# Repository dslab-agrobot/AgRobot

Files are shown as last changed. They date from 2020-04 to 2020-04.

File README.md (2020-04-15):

# AgRobot
Repository for DSLAB AgRobot Project
The file structure should be:

```
.
├── LICENSE
├── README.md
├── doc
│   ├── design
|   ├── hardware
│   ├── implementation
│   ├── integration
│   ├── investigation
│   ├── literature
│   ├── other
│   ├── requirements
│   ├── testing
│   ├── validation
│   └── verification
├── pm
│   ├── meeting_minutes
│   ├── pm_docs
│   ├── progress_documentation
│   └── working_instructions
├── share
│   └── images
│       └── progress
│           └── photos
└── src
    ├── hardware
    ├── management_scripts
    ├── software
    └── tools
```

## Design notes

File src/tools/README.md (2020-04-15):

## Tools

Tools for AI , Embed ,etc
<br>
Each script offer an operation , not a piece of job .

### Table of Contents

  * [AI]
    + [Capture and join pictures(or video) from cameras](imgRec.py)
    + [Capture pictures from camera(shell)](imgRec.sh)
    + [List all USB-device with name](listall.sh)
    + [Simple test for a camera](mag.py)
  * [Embed]
    + [Send cmd to serials (python3)](connector.py)
    + [Send cmd to serials (shell)](file_sender.sh)
  * [Other]
    + [Rename photos for branch share](rename.py)

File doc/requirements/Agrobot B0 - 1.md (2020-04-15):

# Agrobot B0 - Requirements

```
Author: Nicholas Mc Guire
Review: 0.2
Date: May 7, 2019
Expires: Nov 8, 2019
Keywords: B0 requirements, basic data aquisition only.
Status: initial draft, unreviewed
DLC Phase: requiremnts
Ref: TODO add HW manuals
QA: initial review
Tracking: GIT
Format: ascii text
```

## Outline:

Basic collection of requirements based primarily on discussions and
team-meetings as well as some preliminary experimentation to gain rough
limits. These requirements serve as the basis for the design,
implementation and initial operation phase of B0.

## Intent of B0:

  Provide minimal mechanical and electrical/electronic support for
  data quisition on a fixed (track-based) potato-"field" while
  assuring basic (minimal) safety properties.

## Software controlor (Arduino)

 ### Arduino startup 
   - Provide ready signal once booted ? e.g. Pi can 
     request status -> response ready-for-command, busy-calibrate or
     error-state (to be defined !)
 ### Control of 4 drive-motors 
   - Input (from Pi3) relative motion distance/direction e.g.
     (+10cm/-20cm) 
   - Reset information (at end of track) to Pi ?? open-issue
   - Accuracy over the entire track (12m) +/- 3m (durable ?)
 ### Control of y-axis sled motor
   - Input (from Pi3) relative motion command (e.g. +5cm/-10cm)
   - Response Ack (e.g. 0 ok, -1 failed to execute command or
     error code about the failure 1 reset ?? TBD)
   - Reset information to Pi ?? open-issue
   - Accuracy over the entire sled (1m) +/- 2m (duable ?)
 ### Continuous check of end-pos sensors
   - (TOF Ultrasound for X-axis)
   - Read-contacts for y-axis (in discussion)
   - End bumpers on y-axis (ruber aprox 2cm)
   - End wheel catchers for X-axis in dicussion)
 ### Motion requirements
   - X-axis maximum speed 50-80 cm/min
   - Y-axis maximum 30cm/min (roughly 3 minutes for a left-right pass)
   - Reset of absolute 0 every 5m (2.5 passes ? or make that 6m and 
     3 full passes ?)
 ### Power Management requirements 
   - 5V supply for
        - Arduino
        - Raspberry Pi3
        - servo-motors 
        - LEDs
   - 30V for motors (?)
   
    Power supplies need to be sufficiently independent with respect
    to disturbances (notably the 30V!) TBD specify tollerances
    Voltage regulators for 5V and 30V shall be provided on-board
    based on 220V/60Hz source (atleast thats what I think china
    uses ?)

## Mechanical motion requirements

 The track (X-axis) is covered from end-to-end
   - Total travel time roughly 1h
 The sled (Y-axis) is covered from end-to-end
   - a pre-specified (static) number of halting positions is defined
   - continuous motion in discussion
 2 Cameras can be mounted on the Y-axis (USB connected to Pi3) 
 Side-guards on all 4 wheels
   - possitional accuracy on the track +/- 2cm
 Cable caryiage - power and network
 End-plates for reliable ultrasound reflection
   - Material (Al probably ?) TBD
   - Diameter 15cm ? TBD 
 Motors outward oriented - no collision with plants
   - Wheels "point" inward 

## Structural mechanics requirements (bot)

 headway/headroom: (over track) 80-90cm (all structural elements - not 
   counting sensor/actor fixtures)
 clear width: 100cm (ideally the wheels are the inner most point - which
   may be a bit below 100cm (95-96cm clear width between wheels)
 structural length <= 90cm total (including wheels !)
 top-torsion structure
   - couble-frame cage (possibly with surface re-inforcement pannels)
   - height 10-15cm
   - single (uninterrupted) beams on each side
   - corner re-inforcmenets "on demand" TBD
 Whele legs - bending limits/deflection under assumed maximum force (TBD !)
   - sidewards (Y-direction deflectino <= 1cm ?? can we put a lower bound
     on this ?
   - longitudinal (X-direction) deflection <= 0.5cm - if needed insert an
     additional stiffening element between the legs.

## Structural requirements bed

 Soil container dimensions 12x1*0.45m (initially 0.5 but reduced due to
   material availability)
 Double water protection in-side (silicon paint + plastic cover)
 Load distribution to cover 18 m^2 (<= 300kg/m^2 - which is for sure
   below load limits of the roof)
 Side props to support soil pressure (depends on board dimensions and
   quality)
 Tracks on both length side 
   - Min width 7-8cm
   - Surface plane +/- 1cm over the lenthg (should be achievable)
   - One-sided tape-mount for position recording (X-axis)
 Power rail (suspension) for draging of power/network cable
   (drag chain cable carrier or 
 Cabling requirements 
   - Electric cabling provided (220V)
   - Network (100Mbit ?) provided
   - other TBD

## Safety requirements

 The robot frame structure must be grounded !
 The cable caryiage must be grounded !
 The network cable shall be reasonably potential free (Tollerance TBD)
 All power cables shall be protected by adequate cable strain reliefs

Structural mechanics requirements (bot)
 USB cables shall be supported by a kinematic support (or similar)
   to ensure that sled movement can not damage/squeeze the 
   cabling
 Servo cables ? length limit ? TBD - not clear if the servos
   can be connected over 1.2m cable length (voltage drop ?)
 Ultra-sound receiver cables - length limit ? TBD
 I2C <-> PWN-controller cable - mechanical stability TBD

## Application sensor/actor requirements

 Low resolution camera capturing track position (tape) 
 
 ### Condition monitoring
   - Humidity sensor - Accuracy ??
   - Temperature sensor - Accuracy ??
   - Air pressure sensor - Accuracy ??
   - Sample rate 4-6 times per day (TBD)
 ### High-resolution camera for still pictures
   - 1280/720 minimum 
   - 24 bit color resolution
 ### High-resolution camera for video
   - FPS ??
   - resolution ??
   - Format ??
 ### LED lines
   - R/G/B other ?
   - brightness control (e.g. PWM)
 ### 2-axis servo for camera gimbal
 Structural mechanics requirements sensor mounting
   - Still image camera Y-axis sled mounted with  U/V rotation (180)
   - Video camera Y-axis firm straight-down mount
   - stationary low-res Video camera mount-point on leg 10-15 cm 
     above track (test focus range needed)

## Imaging requirements

 Still-image rate ?
 Video format 
 Storage format

## Application processor requirements (Pi3)

 ### Communication/synchronisation Arduino
   - Communication via serial line - clear-text - no security requirements
     o data CRC ?
   - Command send and status receive
     o loging of command sequence
   - Camera imaging commands (synchronized with arduino potition control)
   - Camera gimbaling control and angular recording (probably in image name
     TBD)
 ### Communication requirements Server
   - 100 Mbit or Gbit connection 
   - SSH server 
     o remote login support for non-root user
     o pre-exchanged keys 
     o DSA keys
   - rsync support: rsync over ssh for data retrival (pull from server)
   - defined security policy (TBD)
 ### Sensor handling
   - manage all sensors (implemented in python)
     o I2C bus configuration and handling
     o USB configuration and handling
   - manage LEDs (collor/intensity and sync with imaging subsystem)
 ### Data aquisition and handling
   - dedicated storage media for sensor data (not on root fs)
   - high-resolution and low-resolution camera + still-image camera
   - storage of a full track run locally (estimation:
     o still image <=5 images per y-axis transit, <=50 positions along
       the track - image size (jpeg) <= 500k -- 125MB per full track
       transit.
     o high-resolution vide 30GB per full track transit ??
   - Environment data sensor recording
 ### System monitoring
   - Standard Linux system records (syslog/klog/last)  

## Server requirements

Management data requirements
 ### Weather records for Lanzhou (general - public available records)
   - preferably with a local stored daily weather record
 ### Watering records
   - Amount (number of watering cans - roughly equally filled)
   - Time (+/-30min)
   - Person
 ### Operations records
   - Number of traversals and time and any anomalies
   - Number of photos/video-length per traversal and any anomalies
   - Number of environment sensor records and any anomalies
   - Motion record
     o Motion accuracy at end of track (X-axis)
     o Motion accuracy at reset of sled (Y-axis) roughly how many steps
       needed to reach end-indicator
     o Any abnormal termination of motion    
   - Server record
     o Recording of any operational anomalies related to
       data loss or authentication violation

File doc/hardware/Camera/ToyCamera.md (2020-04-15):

# List

|Name|ShopLink|Note|Num per camera|
|---|---|---|:---:|
|1.Electric focus lens|[Link](https://item.taobao.com/item.htm?spm=a1z09.2.0.0.7d312e8dXiKq8g&id=540927166249&_u=e23cfj5gcc23)|The best one I found in Taobao|1|
|2.Mini step motor driver|[Link](https://item.taobao.com/item.htm?spm=a1z09.2.0.0.7d312e8dXiKq8g&id=572946913506&_u=e23cfj5g69f9)|enough for test|2|
|3.M14 lens base|[Link](https://item.taobao.com/item.htm?spm=a1z09.2.0.0.7d312e8dXiKq8g&id=561669140255&_u=e23cfj5g5a85)|rely on the lens |1|
|4.USB camera module|[Link](https://item.taobao.com/item.htm?spm=a1z09.2.0.0.7d312e8dXiKq8g&id=530503001592&_u=e23cfj5g37c6)|rely on the lens|1|
|5.5v 4count delay|[Link](https://detail.tmall.com/item.htm?id=41231430731&spm=a1z09.2.0.0.7d312e8dXiKq8g&_u=e23cfj5g74d2)|cheap and Free freight|1|
|6.other|cables |DuPont wire, terminal wire, heat shrinkable tube, electric iron sleeve, cardboard sleeve (used to make shell)|NaN|

# Details

[jxt's blog](http://www.lolisaikou.cn/archives/diy%E5%8F%AF%E6%8E%A7%E5%85%89%E5%AD%A6%E5%AF%B9%E7%84%A6%E5%8F%98%E7%84%A6usb%E7%9B%B8%E6%9C%BAver01)

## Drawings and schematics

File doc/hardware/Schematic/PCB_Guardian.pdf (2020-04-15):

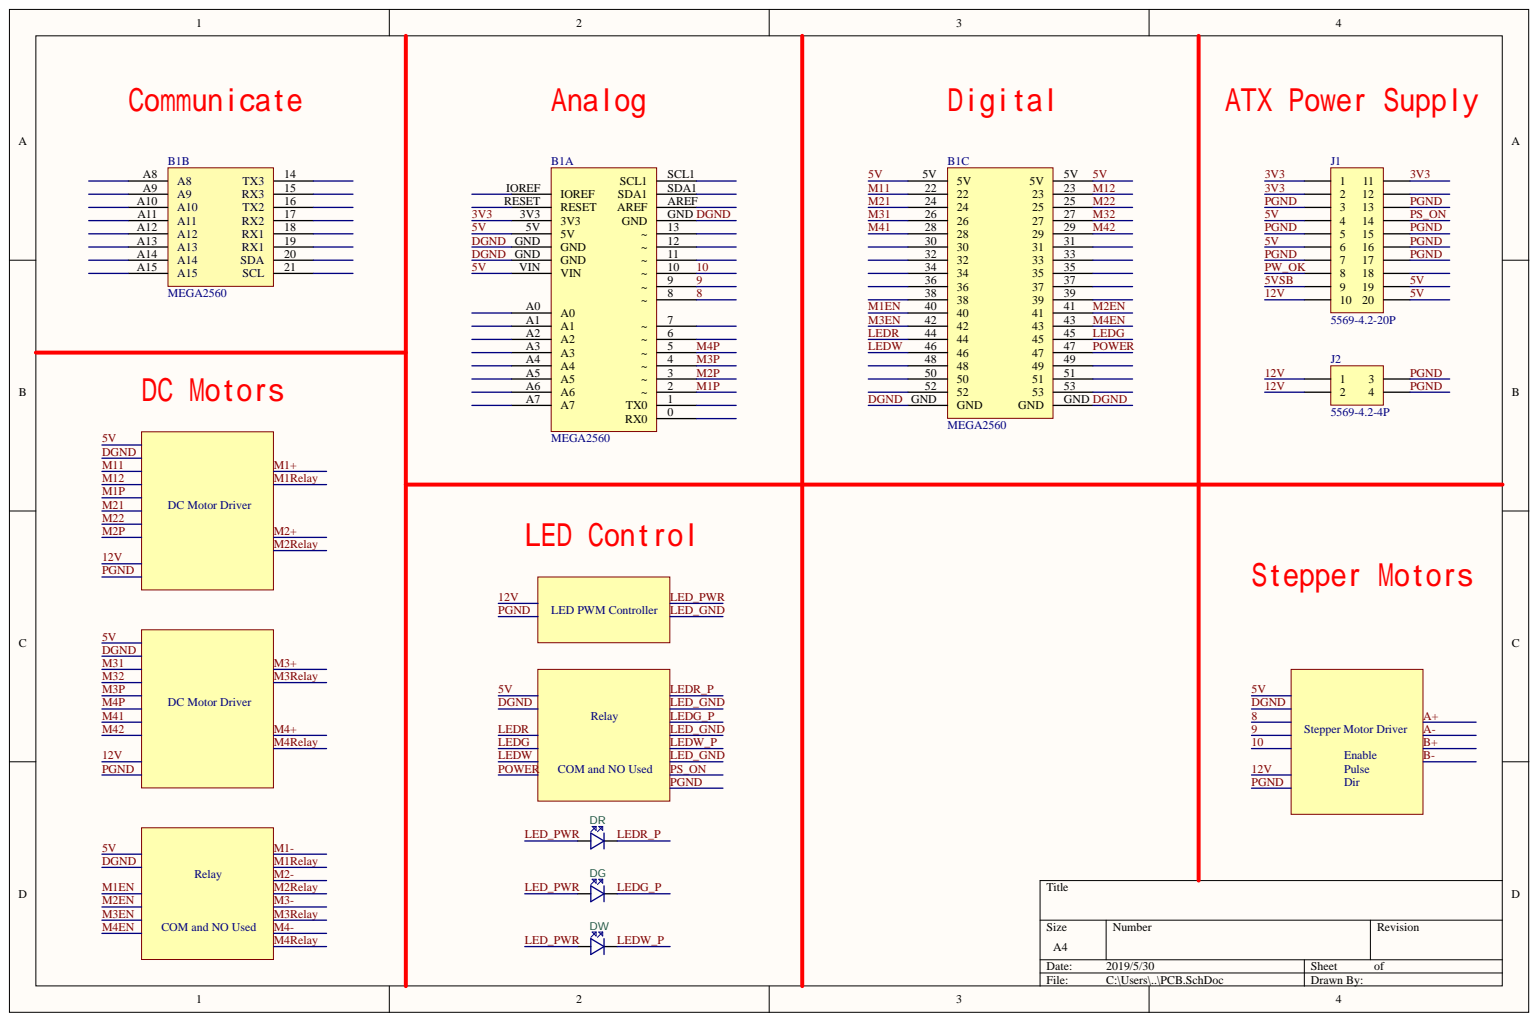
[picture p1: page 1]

COM and NO Used

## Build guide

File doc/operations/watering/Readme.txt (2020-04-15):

This directory saves and updates the record of potato-watering per 3 days.
watering amount was adjusted to 60L/3-days by the biology department members of the project

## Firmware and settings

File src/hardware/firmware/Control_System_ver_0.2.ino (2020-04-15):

/*
   Control System Source Code

                  Version 0.2


   FINISHED

   1. LED and POWER control Function is now added.

   2. Add software limitation to avoid wrong move commands.

   3. Use Hardware limitation to help calibrate the Y-axis.


   TO DO

   1. Add RELIABLE sensor to mesure the distance to the end of the track.



*/
#include <Wire.h>

//Digital Input Pins

//Define Pin Locations for Motors

//DC Motor Pins
//DC Motor 1 for Left-Front Wheel
#define M11 22
#define M12 23
#define M1P 2

//DC Motor 2 for Right-Front Wheel
#define M21 24
#define M22 25
#define M2P 3

//DC Motor 3 for Left-Rear Wheel
#define M31 26
#define M32 27
#define M3P 4

//DC Motor 4 for Right-Rear Wheel
#define M41 28
#define M42 29
#define M4P 5

////Stepper Motor Pins
////Stepper Motor 1 and 2 for X Axis
//#define S1D 30
//#define S1E 31
//#define S1S 32
//
////Stepper Motor 3 for Y Axis
//#define S2D 33
//#define S2E 34
//#define S2S 35

////Stepper Motor 4 for Z Axis
//#define S3D 36
//#define S3E 37
//#define S3S 38

//DC Motors Relay Enable Pin
#define M1EN 40
#define M2EN 41
#define M3EN 42
#define M4EN 43

//Main Power and LED Control Pin
#define LEDR 44
#define LEDG 45
#define LEDW 46
#define POWER 47

//Analog Input Pins
//Battery Pack Voltage, Use Devide Network to Map 0-14.4V to 0-4.096V
//#define Batt_Volt 0
#define LED 13
#define VER 0.2

const int PWM_percent = 100;
const int Steps_per_1mm = 800;

long x_position = 0;
long y_position = 0;
long x_overall = 0;
long y_overall = 0;

bool End_Signal = LOW;

void setup() {
  Serial.begin(115200);
  pinMode(2, OUTPUT);
  pinMode(3, OUTPUT);
  pinMode(4, OUTPUT);
  pinMode(5, OUTPUT);
  pinMode(8, OUTPUT);
  pinMode(9, OUTPUT);
  pinMode(10, OUTPUT);
  pinMode(13, OUTPUT);
  pinMode(22, OUTPUT);
  pinMode(23, OUTPUT);
  pinMode(24, OUTPUT);
  pinMode(25, OUTPUT);
  pinMode(26, OUTPUT);
  pinMode(27, OUTPUT);
  pinMode(28, OUTPUT);
  pinMode(29, OUTPUT);
  pinMode(30, OUTPUT);
  pinMode(31, OUTPUT);
  pinMode(32, OUTPUT);
  pinMode(33, OUTPUT);
  pinMode(34, OUTPUT);
  pinMode(35, OUTPUT);
  pinMode(36, OUTPUT);
  pinMode(37, OUTPUT);
  pinMode(38, OUTPUT);
  pinMode(40, OUTPUT);
  pinMode(41, OUTPUT);
  pinMode(42, OUTPUT);
  pinMode(43, OUTPUT);
  pinMode(44, OUTPUT);
  pinMode(45, OUTPUT);
  pinMode(46, OUTPUT);
  pinMode(47, OUTPUT);

  Serial.println("Y-axis Calibrating!!!");
  digitalWrite(LED, HIGH);
  digitalWrite(10, HIGH);
  digitalWrite(8, 0);
  delay(100);
  for (long i = 0; i < 100000; i++)
  {
    if (End_Signal != HIGH)
    {
      for (long j = 0; j < 100; j++)
      {
        digitalWrite(9, HIGH);
        delay(0.5);
        digitalWrite(9, LOW);
        delay(0.5);
      }
    }
    else
    {
      break;
    }
  }
  delay(100);
  for (long i = 0; i < 20000; i++)
  {
    digitalWrite(9, HIGH);
    delay(0.5);
    digitalWrite(9, LOW);
    delay(0.5);
  }
  delay(100);
  digitalWrite(8, 1);
  Serial.println("Y-axis Calibrated!!!");
  digitalWrite(LED, LOW);
}

void loop()
{
  String comdata = "";
  long x_data = 0;
  long y_data = 0;
  long x_time = 0;
  long y_step = 0;
  bool MIN1 = 0;
  bool MIN2 = 0;
  bool y_dir;

  while (Serial.available() > 0)
  {
    comdata += char(Serial.read());
    delay(2);
  }
  if (comdata.length() > 0)
  {
    Serial.println("Data Received!");
    Serial.println(comdata);
    if (comdata[0] == 'X')
    {
      String x_data_s = "";
      x_data_s = comdata[2];
      x_data_s += comdata[3];
      x_data_s += comdata[4];
      x_data_s += comdata[5];
      x_data = x_data_s.toInt();
      if (comdata[1] == '+')
      {
        x_position += x_data;
        MIN1 = 1;
        MIN2 = 0;
      }
      else if (comdata[1] == '-')
      {
        x_position -= x_data;
        MIN1 = 0;
        MIN2 = 1;
      }
      else
      {
        Serial.println("X-axis Command Error!!!");
        return;
      }
      digitalWrite(LED, HIGH);
      x_time = 2 * 1000 * x_data / PWM_percent;
      //1000 means 1000ms in one second, x_data is Distance in mm
      //PWM_percent / 2 Equals to speed
      //10 is Speed which is Equal 10mm/s, PWM_percent at this time is 100
      digitalWrite(M11, MIN1);
      digitalWrite(M12, MIN2);
      digitalWrite(M21, MIN1);
      digitalWrite(M22, MIN2);
      digitalWrite(M31, MIN1);
      digitalWrite(M32, MIN2);
      digitalWrite(M41, MIN1);
      digitalWrite(M42, MIN2);
      digitalWrite(M1EN, 1);
      digitalWrite(M2EN, 1);
      digitalWrite(M3EN, 1);
      digitalWrite(M4EN, 1);
      delay(200);
      analogWrite(M1P, PWM_percent);
      analogWrite(M2P, PWM_percent);
      analogWrite(M3P, PWM_percent);
      analogWrite(M4P, PWM_percent);
      delay(x_time);
      digitalWrite(M1EN, 0);
      digitalWrite(M2EN, 0);
      digitalWrite(M3EN, 0);
      digitalWrite(M4EN, 0);
      digitalWrite(M11, 0);
      digitalWrite(M12, 0);
      digitalWrite(M21, 0);
      digitalWrite(M22, 0);
      digitalWrite(M31, 0);
      digitalWrite(M32, 0);
      digitalWrite(M41, 0);
      digitalWrite(M42, 0);
      delay(200);
      //x_overall
      x_overall += x_data;
      Serial.print("X-axis Position is:");
      Serial.print(x_position);
      Serial.print("; X has already Moved:");
      Serial.print(x_overall);
      Serial.println(".");
      Serial.println("X-axis Command Executed OK!!!");
      digitalWrite(LED, LOW);
    }
    else if (comdata[0] == 'Y')
    {
      String y_data_s = "";
      y_data_s = comdata[2];
      y_data_s += comdata[3];
      y_data_s += comdata[4];
      y_data = y_data_s.toInt();

      if (comdata[1] == '+')
      {
        y_position += y_data;
        if (y_position > 980)
        {
          Serial.println("Y-axis Command Overrange!!!");
          y_position -= y_data;
          return;
        }
        y_dir = 1;
      }
      else if (comdata[1] == '-')
      {
        y_position -= y_data;
        if (y_position < 10)
        {
          Serial.println("Y-axis Command Overrange!!!");
          y_position += y_data;
          return;
        }
        y_dir = 0;
      }
      else
      {
        Serial.println("Y-axis Command Error!!!");
        return;
      }
      digitalWrite(LED, HIGH);
      y_step = y_data * Steps_per_1mm;
      digitalWrite(10, y_dir);
      digitalWrite(8, 0);
      delay(100);
      for (long i = 0; i < y_step; i++)
      {
        digitalWrite(9, HIGH);
        delay(0.5);
        digitalWrite(9, LOW);
        delay(0.5);
      }
      delay(100);
      digitalWrite(8, 1);
      y_overall += y_data;
      Serial.print("Y-axis Position is:");
      Serial.print(y_position);
      Serial.print("; Y has already Moved:");
      Serial.print(y_overall);
      Serial.println(".");
      if ((y_position == 970) | (y_position == 20))
      {
        Serial.println("Y-axis is at the end.");
      }
      else if ((y_position > 970) | (y_position < 20))
      {
        Serial.println("Y-axis is near the end.");
      }
      Serial.println("Y-axis Command Executed OK!!!");
      digitalWrite(LED, LOW);
    }
    else if (comdata[0] == 'V')
    {
      Serial.print("Firmware Version is ");
      Serial.print(VER);
      Serial.println("!");
    }
    else if (comdata[0] == 'R')
    {
      if (comdata[1] == '+')
      {
        digitalWrite(LEDR, HIGH);
        Serial.println("Red LED Turned ON!!!");
      }
      else if (comdata[1] == '-')
      {
        digitalWrite(LEDR, LOW);
        Serial.println("Red LED Turned OFF!!!");
      }
    }
    else if (comdata[0] == 'G')
    {
      if (comdata[1] == '+')
      {
        digitalWrite(LEDG, HIGH);
        Serial.println("Green LED Turned ON!!!");
      }
      else if (comdata[1] == '-')
      {
        digitalWrite(LEDG, LOW);
        Serial.println("Green LED Turned OFF!!!");
      }
    }
    else if (comdata[0] == 'W')
    {
      if (comdata[1] == '+')
      {
        digitalWrite(LEDW, HIGH);
        Serial.println("White LED Turned ON!!!");
      }
      else if (comdata[1] == '-')
      {
        digitalWrite(LEDW, LOW);
        Serial.println("White LED Turned OFF!!!");
      }
    }
    else if (comdata[0] == 'P')
    {
      if (comdata[1] == '+')
      {
        digitalWrite(POWER, HIGH);
        Serial.println("Main Power Turned ON!!!");
      }
      else if (comdata[1] == '-')
      {
        digitalWrite(POWER, LOW);
        Serial.println("Main Power Turned OFF!!!");
      }
    }
    else
    {
      Serial.println("Command Error!!!");
      return;
    }
  }
}

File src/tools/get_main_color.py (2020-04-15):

#usless code ,we do not use this code any more
#wyq 20190531
import colorsys
import PIL.Image as Image
 
def get_dominant_color(image):
    max_score = 0.0001
    dominant_color = None
    for count,(r,g,b) in image.getcolors(image.size[0]*image.size[1]):
        # 转为HSV标准
        saturation = colorsys.rgb_to_hsv(r/255.0, g/255.0, b/255.0)[1]
        y = min(abs(r*2104+g*4130+b*802+4096+131072)>>13,235)
        y = (y-16.0)/(235-16)
 
        #忽略高亮色
        if y > 0.9:
            continue
        score = (saturation+0.1)*count
        if score > max_score:
            max_score = score
            dominant_color = (r,g,b)
    return dominant_color
 
 
if __name__ == '__main__':
    image = Image.open('test.jpg')
    image = image.convert('RGB')
    print(get_dominant_color(image))

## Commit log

2020-04-15 commit 8295991e0f18b6dd6130639fa28d653418adf623 Author: Yu Liang <50542627+paradox93@users.noreply.github.com> Date: Mon Jun 3 08:35:28 2019 +0800
    Update record.txt
    commit 0fe3d6bd9500fee68205aae1a8622cc3d53c7195
    Author: WeiYongqiang55 <wyq_l@qq.com>
    Date: Fri May 31 20:52:44 2019 +0800
    add kingou mail
    commit db8a9e0390b2a8389494b5fa4a5fbf1f43cf42d8
    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
    [PCB_Guardian.SchDoc]
2020-04-15 add camera list
